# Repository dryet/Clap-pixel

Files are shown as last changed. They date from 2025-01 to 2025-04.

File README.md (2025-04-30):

## Neopixel based light
This repository contains PCB design files, 3D printable cover and code for neopixel based light which turns ON and OFF on two claps.
The PCB was manufactured at JLCPCB.com and the cover was printed using transluscent PLA filament.
STM32CubeMX can be used to modifi the `.ioc` file which generates basic structure for the STM32G0 codebase. Code compilation is done using the STM32CubeCLT.

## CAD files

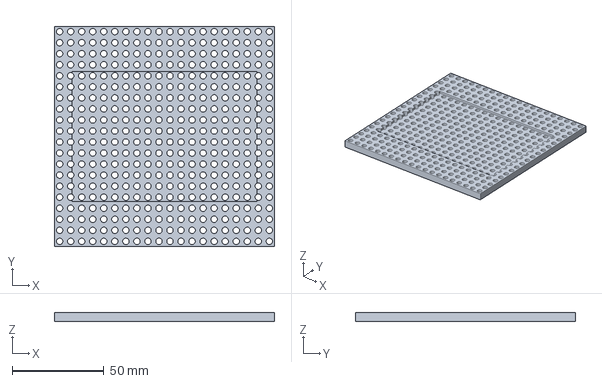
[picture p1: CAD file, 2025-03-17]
3D_print/stencil_PCB_holder_template.FCStd
119.6 x 119.6 x 5.00 mm

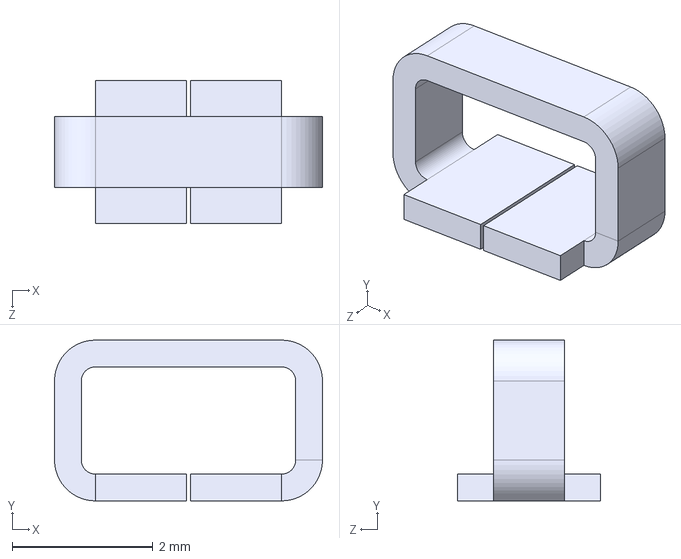
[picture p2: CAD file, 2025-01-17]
Clap-pixel-board/local/Local_3dmodels/5019.STEP
3.81 x 2.29 x 2.03 mm

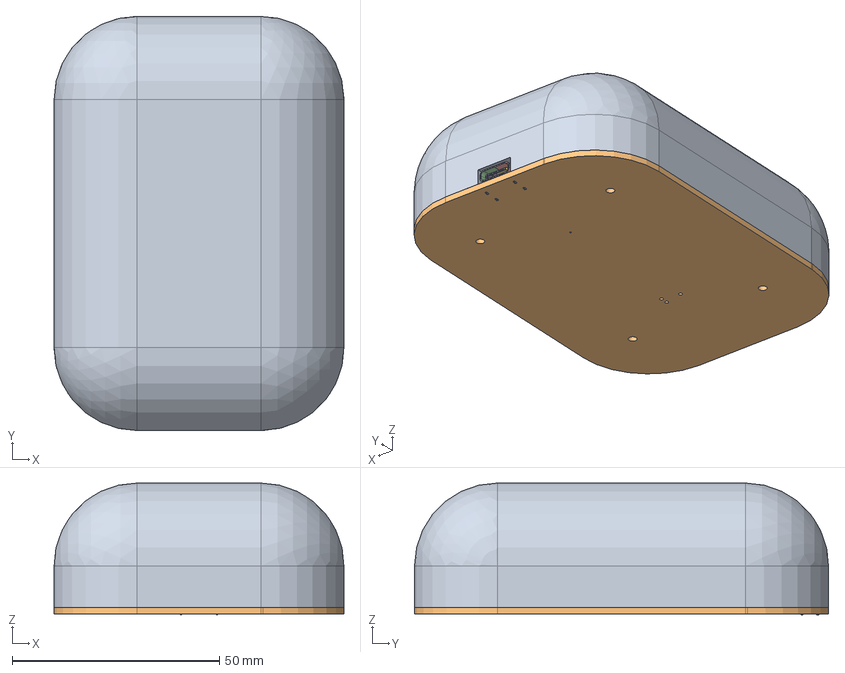
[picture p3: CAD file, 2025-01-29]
3D_print/Clap-pixel-diffuser.FCStd
70.0 x 100.0 x 31.9 mm
C_0402_1005Metric
WS2812-2020
WS2812-2021
WS2812-2022
WS2812-2023
WS2812-2024
WS2812-2025
SOT-23-3
C_0603_1608Metric
C_0402_1005Metric002
C_0603_1608Metric002
C_0402_1005Metric004
SOT_353_SC_70_5
LQFP_48_7x7mm_P05mm
C_0402_1005Metric006
C_0402_1005Metric008
USB_C_Receptacle_GCT_USB4125-xx-x_6P_TopMnt_Horizontal
USB_C_Receptacle_GCT_USB4125-xx-x_6P_TopMnt_Horizontal001
USB_C_Receptacle_GCT_USB4125-xx-x_6P_TopMnt_Horizontal002
USB_C_Receptacle_GCT_USB4125-xx-x_6P_TopMnt_Horizontal003
USB_C_Receptacle_GCT_USB4125-xx-x_6P_TopMnt_Horizontal004
USB_C_Receptacle_GCT_USB4125-xx-x_6P_TopMnt_Horizontal005
USB_C_Receptacle_GCT_USB4125-xx-x_6P_TopMnt_Horizontal006
USB_C_Receptacle_GCT_USB4125-xx-x_6P_TopMnt_Horizontal007
USB_C_Receptacle_GCT_USB4125-xx-x_6P_TopMnt_Horizontal008
USB_C_Receptacle_GCT_USB4125-xx-x_6P_TopMnt_Horizontal009
USB_C_Receptacle_GCT_USB4125-xx-x_6P_TopMnt_Horizontal010
USB_C_Receptacle_GCT_USB4125-xx-x_6P_TopMnt_Horizontal011
USB_C_Receptacle_GCT_USB4125-xx-x_6P_TopMnt_Horizontal012
USB_C_Receptacle_GCT_USB4125-xx-x_6P_TopMnt_Horizontal013
USB_C_Receptacle_GCT_USB4125-xx-x_6P_TopMnt_Horizontal014
USB_C_Receptacle_GCT_USB4125-xx-x_6P_TopMnt_Horizontal015
C_0402_1005Metric010
PinHeader_2x07_P127mm_Vertical_SMD
WS2812-2028
WS2812-2029
WS2812-2030
WS2812-2031
WS2812-2032
WS2812-2033
C_0402_1005Metric012
C_0402_1005Metric014
C_0402_1005Metric016
R_0402_1005Metric
WS2812-2036
WS2812-2037
WS2812-2038
WS2812-2039
WS2812-2040
WS2812-2041
R_0402_1005Metric002
C_0402_1005Metric018
C_0402_1005Metric020
WS2812-2044
WS2812-2045
WS2812-2046
WS2812-2047
WS2812-2048
WS2812-2049
WS2812-2052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

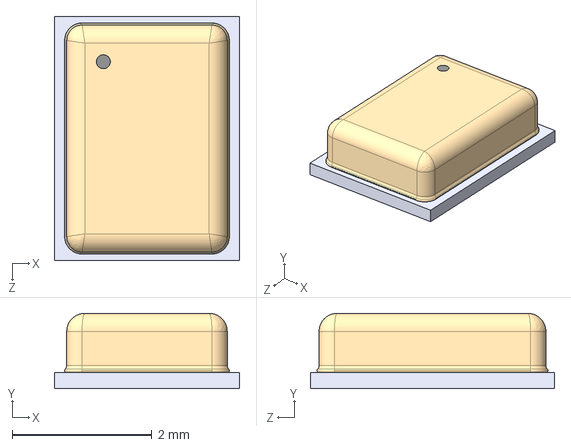
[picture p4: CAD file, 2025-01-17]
Clap-pixel-board/local/Local_3dmodels/MP23ABS1TR.step
2.65 x 1.08 x 3.50 mm

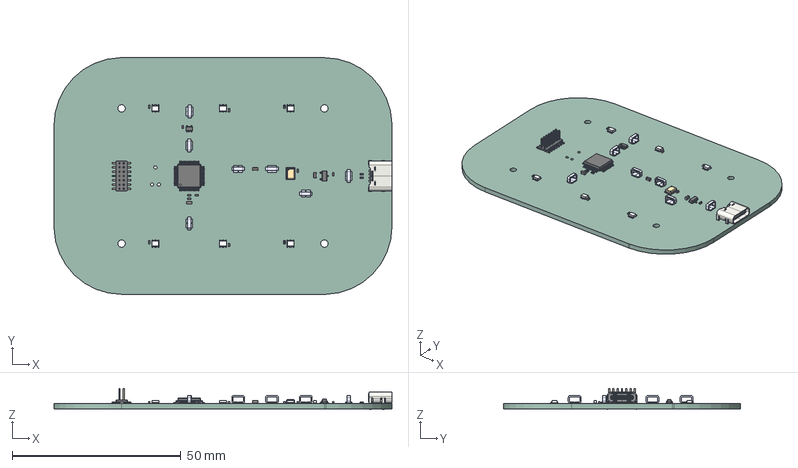
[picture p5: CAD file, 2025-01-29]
3D_print/Clap-pixel-board.step
100.0 x 70.0 x 6.30 mm
C_0402_1005Metric x 12
WS2812-2020 x 6
SOT-23-3
C_0603_1608Metric x 3
SOT_353_SC_70_5
LQFP_48_7x7mm_P05mm
USB_C_Receptacle_GCT_USB4125-xx-x_6P_TopMnt_Horizontal
PinHeader_2x07_P127mm_Vertical_SMD
R_0402_1005Metric x 2
MP23ABS1
Clap-pixel-board_PCB

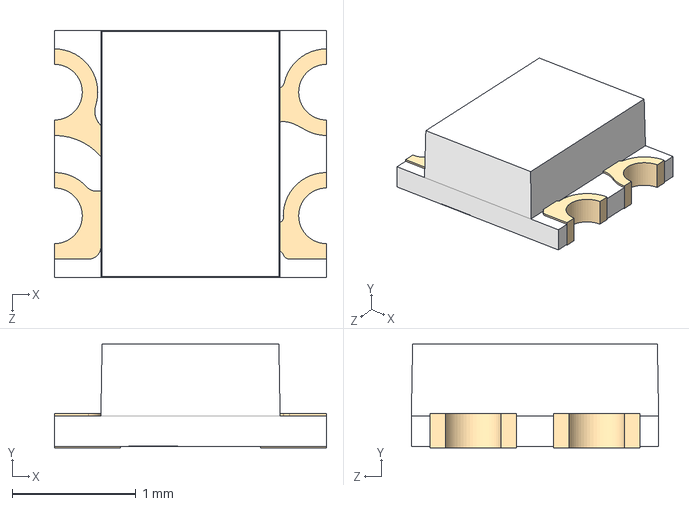
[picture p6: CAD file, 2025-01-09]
Clap-pixel-board/local/Local_3dmodels/WS2812-2020.step
2.20 x 0.84 x 2.00 mm

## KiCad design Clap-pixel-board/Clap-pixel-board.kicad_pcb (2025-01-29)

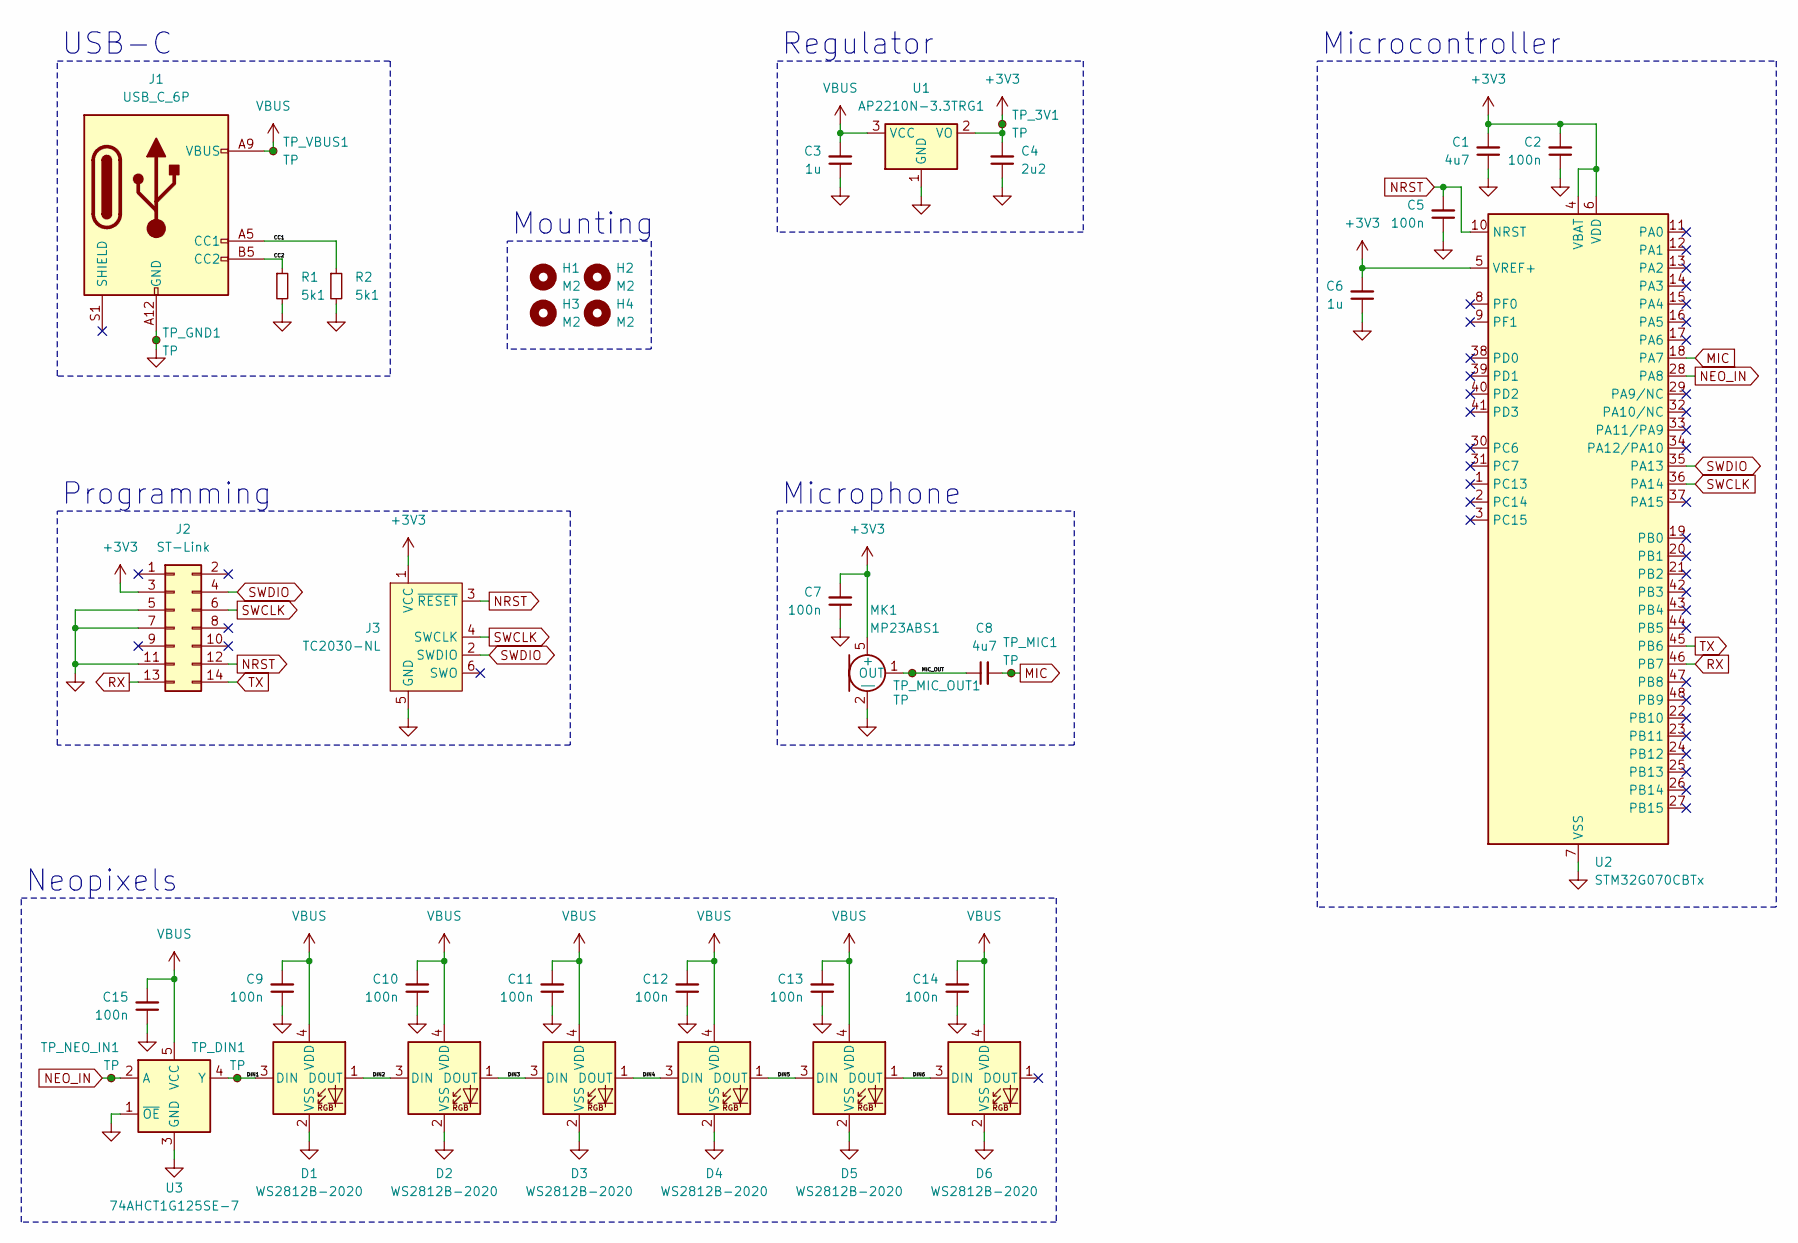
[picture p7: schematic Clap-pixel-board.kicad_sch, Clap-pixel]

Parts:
C1, C8: 4u7; C_0603_1608Metric
C2, C5, C7, C9, C10, C11, C12, C13, C14, C15: 100n; C_0402_1005Metric
C3, C6: 1u; C_0402_1005Metric
C4: 2u2; C_0603_1608Metric
D1, D2, D3, D4, D5, D6: WS2812B-2020; LED_WS2812B-2020_PLCC4_2.0x2.0mm
H1, H2, H3, H4: M2; MountingHole_2.2mm_M2
J1: USB_C_6P; USB_C_Receptacle_GCT_USB4125-xx-x-0190_6P_TopMnt_Horizontal
J2: ST-Link; PinHeader_2x07_P1.27mm_Vertical_SMD
J3: TC2030-NL; Tag-Connect_TC2030-IDC-NL_2x03_P1.27mm_Vertical
MK1: MP23ABS1; MIC_MP23ABS1TR
R1, R2: 5k1; R_0402_1005Metric
TP_3V1: TP; TestPoint_Keystone_5019_Minature
TP_DIN1: TP; TestPoint_Keystone_5019_Minature
TP_GND1: TP; TestPoint_Keystone_5015_Micro-Minature
TP_MIC1: TP; TestPoint_Keystone_5015_Micro-Minature
TP_MIC_OUT1: TP; TestPoint_Keystone_5015_Micro-Minature
TP_NEO_IN1: TP; TestPoint_Keystone_5019_Minature
TP_VBUS1: TP; TestPoint_Keystone_5015_Micro-Minature
U1: AP2210N-3.3TRG1; SOT-23-3
U2: STM32G070CBTx; LQFP-48_7x7mm_P0.5mm
U3: 74AHCT1G125SE-7; SOT-353_SC-70-5

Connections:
+3V3: C1.2, C2.2, C4.2, C6.2, C7.2, J2.3, J3.1 (VCC), MK1.5 (+), TP_3V1.1, U1.2 (VO), U2.4 (VBAT), U2.5 (VREF+), U2.6 (VDD)
/CC1: J1.A5 (CC1), R2.1
/CC2: J1.B5 (CC2), R1.1
/DIN1: D1.3 (DIN), TP_DIN1.1, U3.4 (Y)
/DIN2: D1.1 (DOUT), D2.3 (DIN)
/DIN3: D2.1 (DOUT), D3.3 (DIN)
/DIN4: D3.1 (DOUT), D4.3 (DIN)
/DIN5: D4.1 (DOUT), D5.3 (DIN)
/DIN6: D5.1 (DOUT), D6.3 (DIN)
/MIC_OUT: C8.1, MK1.1 (OUT), TP_MIC_OUT1.1
GND: C1.1, C2.1, C3.1, C4.1, C5.1, C6.1, C7.1, C9.1, C10.1, C11.1, C12.1, C13.1, C14.1, C15.1, D1.2 (VSS), D2.2 (VSS), D3.2 (VSS), D4.2 (VSS), D5.2 (VSS), D6.2 (VSS), J1.A12 (GND), J1.B12 (GND), J2.5, J2.7, J2.11, J3.5 (GND), MK1.2 (|), MK1.3 (-), MK1.4 (-), R1.2, R2.2, TP_GND1.1, U1.1 (GND), U2.7 (VSS), U3.1 (~OE), U3.3 (GND)
MIC: C8.2, TP_MIC1.1, U2.18 (PA7)
NEO_IN: TP_NEO_IN1.1, U2.28 (PA8), U3.2 (A)
NRST: C5.2, J2.12, J3.3 (~RESET), U2.10 (NRST)
RX: J2.13, U2.46 (PB7)
SWCLK: J2.6, J3.4 (SWCLK), U2.36 (PA14)
SWDIO: J2.4, J3.2 (SWDIO), U2.35 (PA13)
TX: J2.14, U2.45 (PB6)
VBUS: C3.2, C9.2, C10.2, C11.2, C12.2, C13.2, C14.2, C15.2, D1.4 (VDD), D2.4 (VDD), D3.4 (VDD), D4.4 (VDD), D5.4 (VDD), D6.4 (VDD), J1.A9 (VBUS), J1.B9 (VBUS), TP_VBUS1.1, U1.3 (VCC), U3.5 (VCC)

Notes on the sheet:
Mounting
Microphone
Neopixels
Microcontroller
Programming
Regulator
USB-C

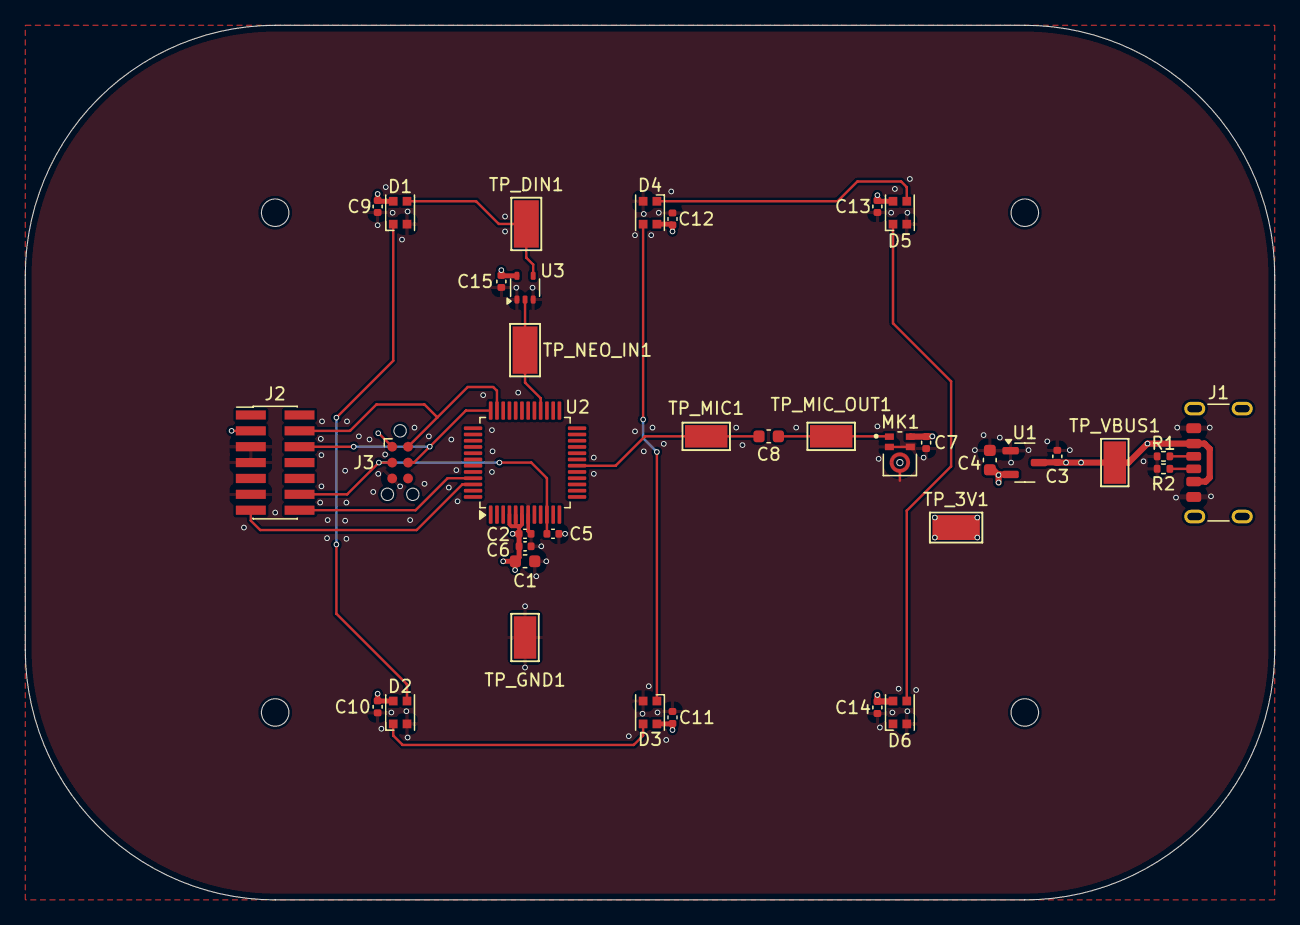
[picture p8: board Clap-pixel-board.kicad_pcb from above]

Board: 4 copper layers, 100.0 x 70.0 mm, 41 parts (0 on the bottom side), 19 nets.

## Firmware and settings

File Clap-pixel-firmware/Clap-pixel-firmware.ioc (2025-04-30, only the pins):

Mcu.UserName=STM32G070CBTx
PA13.Signal=SYS_SWDIO
PA14-BOOT0.Signal=SYS_SWCLK
PA7.Signal=ADC1_IN7
PA8.Signal=S_TIM1_CH1
PB6.Signal=USART1_TX
PB7.Signal=USART1_RX

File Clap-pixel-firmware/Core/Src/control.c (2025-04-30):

/*
 * control.c
 *
 *  Created on: Apr 30, 2025
 *      Author: Petr Opravil
 */

#include <stdio.h>
#include "adc.h"
#include "usart.h"
#include "control.h"
#include "neopixel.h"

#define LED_COLOR_DELAY 150
#define LED_SATURATION_VALUE 200

#define LED_HIGH_VALUE 200
#define LED_HIGH_THRESHOLD 20
#define LED_LOW_THRESHOLD 8
#define LED_BUFFER_TIME_MS 30
#define LED_LOW_TIME_MS 140
#define LED_RESET_TIME_MS 750
#define LED_DEBOUNCE_TIME_MS 1000

enum clap_state_e
{
  WAIT_FIRST,
  BUFFER,
  STAY_LOW,
  WAIT_SECOND,
  TURN_ON
};
enum clap_state_e clap_state;
uint16_t cnt_timer = 0;

uint32_t mic_raw_data;
uint16_t mic_prev_data;

uint16_t led_value = 0;

uint16_t hue;

#ifdef __GNUC__
/* With GCC/RAISONANCE, small printf (option LD Linker->Libraries->Small printf
   set to 'Yes') calls __io_putchar() */
#define PUTCHAR_PROTOTYPE int __io_putchar(int ch)
#else
#define PUTCHAR_PROTOTYPE int fputc(int ch, FILE *f)
#endif /* __GNUC__ */

void Control_Init () {
    hue = 0;
    HAL_ADC_Start_DMA(&hadc1, &mic_raw_data, 1);
}

void Control_Loop () {
    hue += 2;
    if (hue > 255)
    {
      hue = 0;
    }
    neopixel_set_color_hsv(hue, LED_SATURATION_VALUE, led_value);
    HAL_Delay(LED_COLOR_DELAY);
}

void ADC_update_on_tick(void)
{
  cnt_timer--;

  if (!cnt_timer)
  {
    switch (clap_state)
    {
    case BUFFER:
      clap_state = STAY_LOW;
      cnt_timer = LED_LOW_TIME_MS;
      break;
    case STAY_LOW:
      clap_state = WAIT_SECOND;
      cnt_timer = LED_RESET_TIME_MS;
      break;
    case WAIT_SECOND:
      clap_state = WAIT_FIRST;
      break;
    case TURN_ON:
      clap_state = WAIT_FIRST;
      HAL_ADC_Start_DMA(&hadc1, &mic_raw_data, 1);
      break;
    default:
      break;
    }
  }
}

/**
 * @brief  End Of Sampling callback in non-blocking mode.
 * @param hadc ADC handle
 * @retval None
 */
void HAL_ADC_ConvCpltCallback(ADC_HandleTypeDef *hadc)
{
  UNUSED(hadc);

  uint16_t abs_value;
  int16_t difference;

  difference = mic_prev_data - mic_raw_data;
  mic_prev_data = mic_raw_data;
  if (difference < 0)
  {
    abs_value = (difference ^ 0xFFFF) + 1;
  }
  else
  {
    abs_value = difference;
  }
  assert_param(abs_value < 4096);
  printf("%u\n\r", abs_value);

  switch (clap_state)
  {
  case WAIT_FIRST:
    if (abs_value > LED_HIGH_THRESHOLD)
    {
        clap_state = BUFFER;
        cnt_timer = LED_BUFFER_TIME_MS;
    }
    break;
  case STAY_LOW:
    if (abs_value > LED_LOW_THRESHOLD)
    {
        clap_state = WAIT_FIRST;
    }
    break;
  case WAIT_SECOND:
    if (abs_value > LED_HIGH_THRESHOLD)
    {
        led_value = led_value ? 0 : LED_HIGH_VALUE;
        clap_state = TURN_ON;
        cnt_timer = LED_DEBOUNCE_TIME_MS;
        mic_raw_data = 0;
    }
    break;
  default:
    break;
  }

  if (clap_state != TURN_ON)
  {
    HAL_ADC_Start_DMA(&hadc1, &mic_raw_data, 1);
  }
}

PUTCHAR_PROTOTYPE
{
  HAL_UART_Transmit(&huart1, (uint8_t *)&ch, 1, HAL_MAX_DELAY);

  return ch;
}

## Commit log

2025-01-09 Added KiCAD project
    [Clap-pixel-board.kicad_pcb, Clap-pixel-board.kicad_sch]
2025-01-09 Create local folder
    [WS2812-2020.step]
2025-01-17 Schematic finished
    [5019.STEP, Clap-pixel-board.kicad_pcb, Clap-pixel-board.kicad_sch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]
2025-01-29 Finished PCB
    [Clap-pixel-board.kicad_pcb]
2025-01-29 Add 3D files
    [Clap-pixel-board.step, Clap-pixel-diffuser.FCStd]
2025-03-17 Lights work now
    [Clap-pixel-board.kicad_sch, stencil_PCB_holder_template.FCStd]
